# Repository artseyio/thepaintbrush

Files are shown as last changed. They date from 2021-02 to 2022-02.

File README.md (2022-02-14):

# The Paintbrush

A small keyboard design for those who cannot or prefer not use 'traditional' keyboard designs.

*This project aims to create a small keyboard design that is adaptable and flexible. Especially for those with disabilities, those who cannot type on traditional keyboads and those that prefer not use traditional keyboards.*

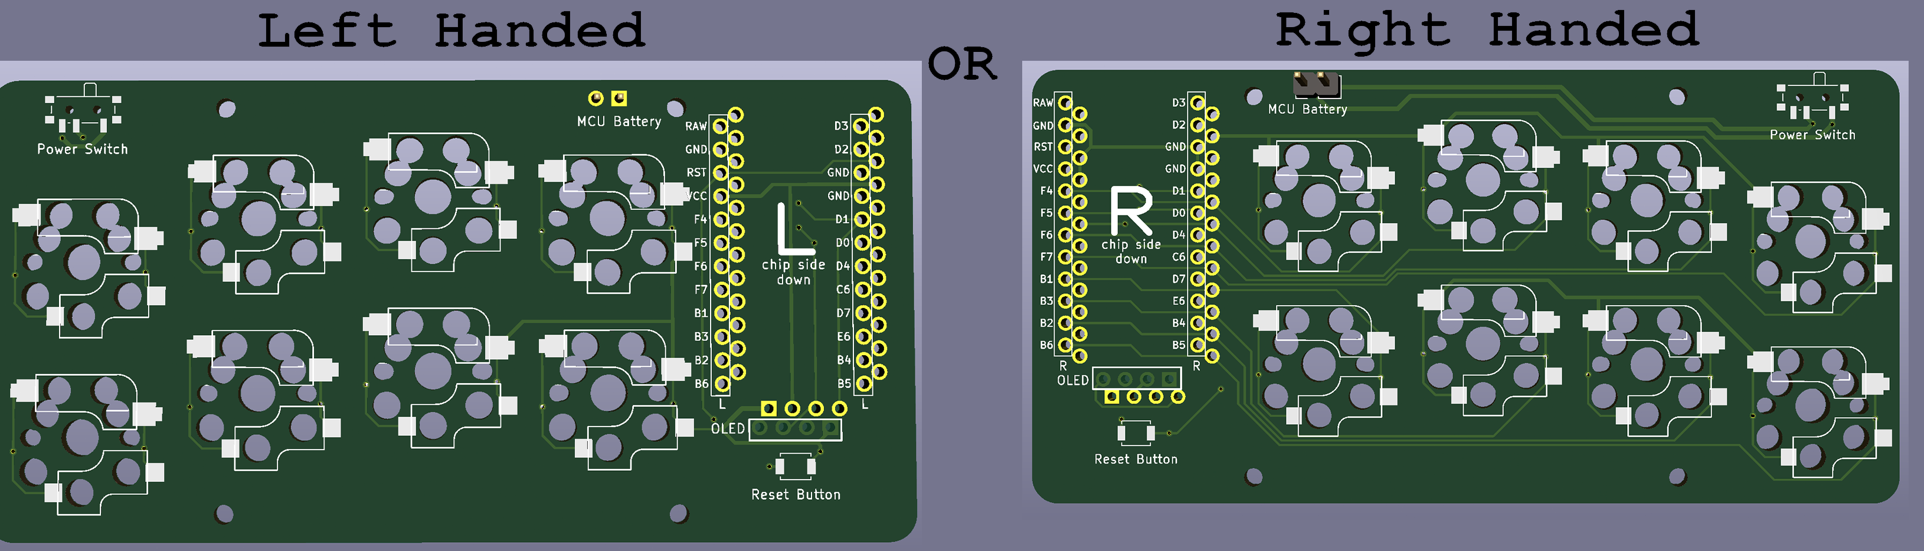
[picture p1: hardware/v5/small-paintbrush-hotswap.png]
Version 5 Rendering


## Versions

The current version of The Painbrush is [version 5](hardware/v5).

*Please refer to the version folders for additional details on building as well as bill of materials.*

## Firmware

QMK and ZMK reference code can be found at [qmk-artsey](https://github.com/artseyio/qmk-artsey/) and [zmk-artsey](https://github.com/artseyio/zmk-artsey/) respectively.

## PCB/Plate Ordering

### PCB

If you'd like to order a PCB you'll need either the main KiCAD file (the ones ending in .pro) or the gerber files (the zip files in the gerber folders). Most PCB makers will ask for ```gerber files``` which will be the zip files in the appropriate ```gerber``` folder. In each hardware revision's folder there will be bottom plate PCB files (KiCAD and gerber) as well as the main PCB files (KiCAD and gerber).

We have been able to confirm both [OSH Park](https://oshpark.com/) and [JLCPCB](https://jlcpcb.com/) can make the paintbrush PCBs.

JLCPCB is usually pretty cheap, even with a minimum order quanity of 5 PCBs. In many cases you can get 5 paintbrush PCBs for under $10 USD if you don't select super fast service or additional options.

### Switch Plate

The switch plate can be made by a number of different companies and there is a file in each hardware revision that ends in ```.step```.

We have been able to confirm [ShapeWays](https://shapeways.com/) and [JLCPCB](https://jlcpcb.com/) have been a very reliable source. They offer a wide range of materials at different price points.

You can also get the switch plate made from a company that does laser cutting but we have not heard which companies may be the best option from the community yet.

### Bottom Plate

The bottom plate can be made by a number of different companies and there is a file in each hardware revision that ends in ```.step```.

We have been able to confirm [ShapeWays](https://shapeways.com/) has been a very reliable source for on demand 3d printing. They offer a wide range of materials at different price points.

You can also get the bottom plate made from a company that does laser cutting but we have not heard which companies may be the best option from the community yet.

## What

A small keyboard hardware design that can be built free of charge for non-commercial use. The design is meant to be used with systems like [ARTSEY.IO](https://www.artsey.io/).

We also work to have our hardware supported by well known open source keyboard firmware projects to make them easier to setup and use.

## Why

There are few keyboard options for those with hand disabilities. The few commercial keyboards 'designed' to address hand disabilities are incredibly expensive and aren't well designed if you consider risk of long term RSI related problems. This project was founded to address these systemic issues.

## Who

Just a human who has had their left hand immobilized for 6 weeks and their right hand injured badly enough to cause typing problems on traditional keyboards for 2 weeks.

## Licensing

Unless otherwise stated all source code is licensed under the [Apache 2 License](LICENSE-APACHE-2.0.txt).

Unless otherwise state all hardware designs are licensed under the [CERN Open Hardware Licence Version 2 - Weakly Reciprocal License](LICENSE-cern_ohl_w_v2.txt).

Unless otherwise stated the non source code and non hardware design contents of this repository are licensed under a [Creative Commons Attribution-NonCommercial-ShareAlike 4.0 International License](LICENSE-CC-Attribution-NonCommercial-ShareAlike-4.0-International.txt)

## Commercial Licencing

If you're interested in commercial licencing of our designs, please contact KemoNine for details. Their e-mail can be found in the git log. When contacting KemoNine please include (at a minimum) your name, your company/store's website, how you plan to sell the designs and why you'd like to sell the designs.

*Please note: this applies to ANY sales that are not 'at cost' or would result in a profit (online stores, group buys, sales to friends, etc)*

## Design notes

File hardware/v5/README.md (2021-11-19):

# Paintbrush Version 5

This is the fifh hardware design of the Paintbrush mini keyboard. This version adds MX switch support, a plate for MX builds and moves the MCU to a better location to accomodate thicker USB cables. The silk screens were also overhauled and can be used to guide a build without referencing these instructions.

Please see the following sections for details about this hardware version.

## Rendering

Version 5 Rendering

## Features

- *Reversable* PCB
  - Can be built left *OR* right handed
- Pro Micro compatible MCU foot print
- Kalih Choc v1 mechanical switches *OR* MX mechanical switches
- OLED support (optional)
- Slide switch that can be used as a power switch (optional)
- Switch plate (required for MX switch builds)
- Reset button (optional)
- Bottom plate (optional)

## Bill of Materials

Please note: the provided links are for reference. Most of these products can be found in more than one store.

For MX switch builds you'll need a switch plate, hot swap sockets and switches for your build. The below switch and socket options are for choc switch builds.

| Component | Part Information | Quantity | Purchase |
| --- | --- | --- | --- |
| Pro Micro MCU | Any pro micro compatible MCU that supports ZMK or QMK | 1 | N/A |
| Kalih Choc v1 Switches | Kailh low profile Switch 1350 Chocolate Keyboard Switch | 8 | [AliExpress](https://www.aliexpress.com/item/32959996455.html) |
| Kalih Hot Swap Sockets (optional if directly soldering switches) | Kailh hot swap Socket for low profile 1350 Chocolate Switches | 8 | [AliExpress](https://www.aliexpress.com/item/33023283633.html) |
| Optional OLED | Any SSD1306 I2C OLED supported by or ZMK | 1 | N/A |
| Optional Power Switch | C&K PCM12SMTR | 1 | [DigiKey](https://www.digikey.com/en/products/detail/c-k/PCM12SMTR/1640112?s=N4IgTCBcDaIAoGECyBGCBdAvkA) |
| Optional Reset button | Omron Electronics Inc-EMC Div B3U-1000P | 1 | [DigiKey](https://www.digikey.com/en/products/detail/omron-electronics-inc-emc-div/B3U-1000P/1534338) |
| Optional Bottom Plate | The bottom plate for the PCB, attach with M2 stand offs and screws | 1 | N/A |
| Optional M2 stand offs | Stand offs can be used to attach the bottom plate or add a mild angle to the obard | 2-4 | N/A |
| Optional Battery | A *lithium* battery for powering the board, we recommend 10440 or lithium polymer batteries | 1 | N/A |

## Bottom Plate

The bottom plate is wholly optional for this build. We strongly recommend including it as part of your PCB order or 3d printing it in [PA12](https://www.shapeways.com/materials/multi-jet-fusion-pa12/) or [PA12-GB](https://www.shapeways.com/materials/multi-jet-fusion-pa12gb/) at [ShapeWays](https://www.shapeways.com/) if you want a bottom plate.

The bottom plate is available as a [step file](small-paintbrush-hotswap-bottom.step) if you'd like to have it created via CNC or 3d printing independent of your PCB order.

The bottom plate can be attached using standard M2 stand offs and screws.

## Build Instructions

1. Solder hot swap sockets
    - Please note: the sockets are soldered to the **underside** of the PCB
1. Solder power switch if being used
1. Solder reset button if being used
1. Solder pro micro compatible mcu
1. Solder OLED if being used
1. Solder one pad of power header to appropriate pro micro pin if being used
1. Solder battery to power header (if being used) and ground
1. Populate switches if using hot swap sockets
1. Flash chosen firmware

## Soldering Quick References

### Left Handed Builds

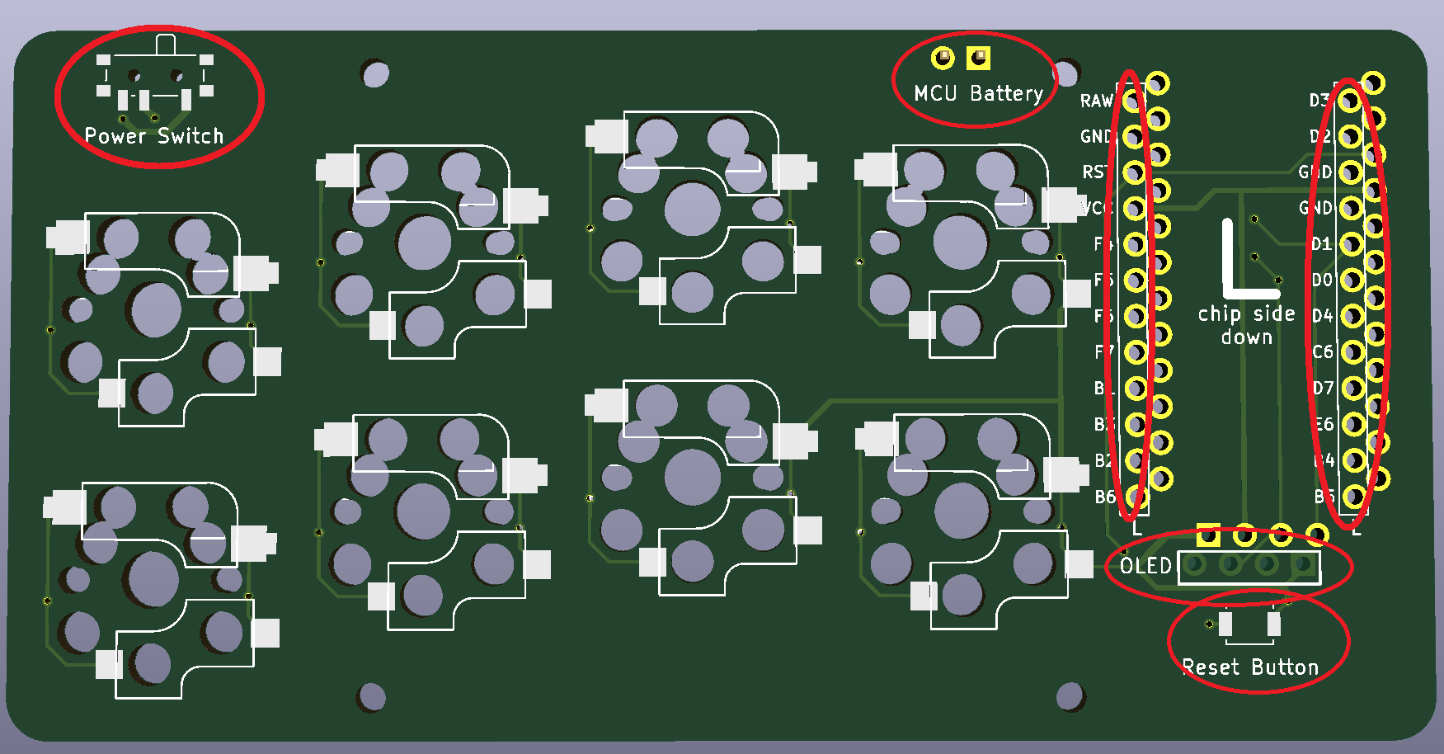
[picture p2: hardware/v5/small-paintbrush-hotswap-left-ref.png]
Version 5 Left Handed Build Quick Ref


### Right Handed Builds

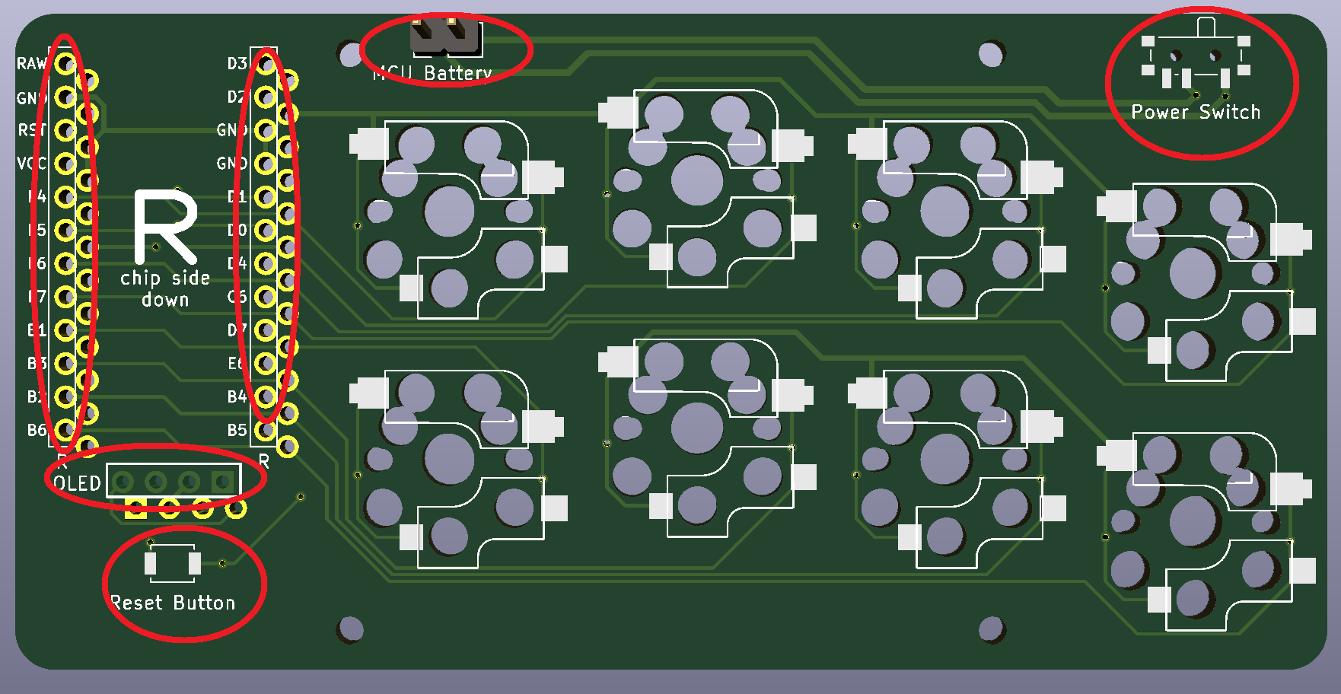
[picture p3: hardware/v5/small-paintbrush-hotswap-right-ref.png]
Version 5 Right Handed Build Quick Ref


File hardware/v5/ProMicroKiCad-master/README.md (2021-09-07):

Pro Micro library for KiCAD
=======================================

This repo includes Pro Micro library.

### Variants
* ProMicro.kicad_mod - The default variant
* ProMicro-NoSilk.kicad_mod - No silkscreen guides
* ProMicro-EnforcedTop.kicad_mod - Covers the Pro Micro side of all pads with soldermask to make reverse-side mounting impossible.

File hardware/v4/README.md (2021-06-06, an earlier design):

# Paintbrush Version 4

This is the fourth hardware design of the Paintbrush mini keyboard. This version removes the 'leg' from version 3 and moves the secondary features (switch/reset button) to a more user friendly location at the top of the board.

Please see the following sections for details about this hardware version.

## Rendering

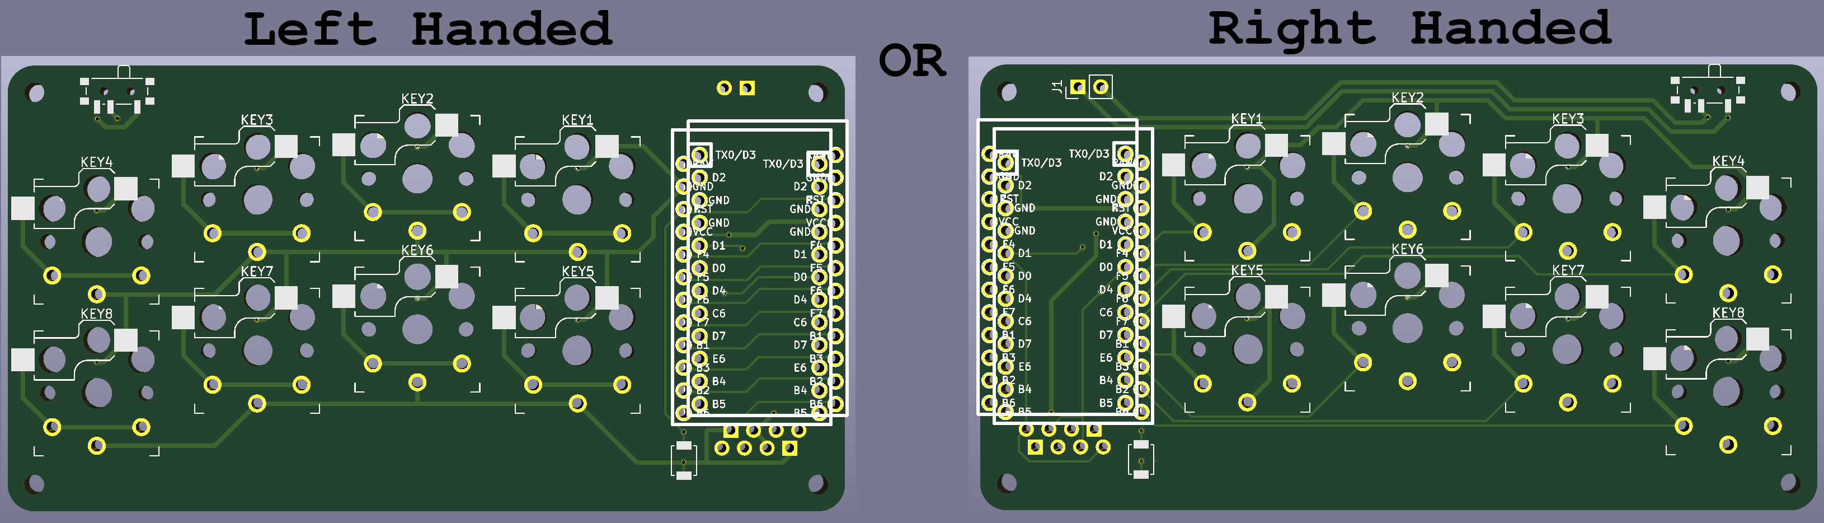
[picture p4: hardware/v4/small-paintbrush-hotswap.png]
Version 4 Rendering


## Features

- *Reversable* PCB
  - Can be built left *OR* right handed
- Pro Micro compatible MCU foot print
- Kalih Choc v1 mechanical switches
  - Soldered directly *OR* using kalih hot swap sockets
- OLED support (optional)
- Slide switch that can be used as a power switch (optional)
- Reset button (optional)
- Bottom plate (optional)

## Bill of Materials

Please note: the provided links are for reference. Most of these products can be found in more than one store.

| Component | Part Information | Quantity | Purchase |
| --- | --- | --- | --- |
| Pro Micro MCU | Any pro micro compatible MCU that supports ZMK or QMK | 1 | N/A |
| Kalih Choc v1 Switches | Kailh low profile Switch 1350 Chocolate Keyboard Switch | 8 | [AliExpress](https://www.aliexpress.com/item/32959996455.html) |
| Kalih Hot Swap Sockets (optional if directly soldering switches) | Kailh hot swap Socket for low profile 1350 Chocolate Switches | 8 | [AliExpress](https://www.aliexpress.com/item/33023283633.html) |
| Optional OLED | Any SSD1306 I2C OLED supported by or ZMK | 1 | N/A |
| Optional Power Switch | C&K PCM12SMTR | 1 | [DigiKey](https://www.digikey.com/en/products/detail/c-k/PCM12SMTR/1640112?s=N4IgTCBcDaIAoGECyBGCBdAvkA) |
| Optional Reset button | Omron Electronics Inc-EMC Div B3U-1000P | 1 | [DigiKey](https://www.digikey.com/en/products/detail/omron-electronics-inc-emc-div/B3U-1000P/1534338) |
| Optional Bottom Plate | The bottom plate for the PCB, attach with M2 stand offs and screws | 1 | N/A |
| Optional M2 stand offs | Stand offs can be used to attach the bottom plate or add a mild angle to the obard | 2-4 | N/A |
| Optional Battery | A *lithium* battery for powering the board, we recommend 10440 or lithium polymer batteries | 1 | N/A |

## Bottom Plate

The bottom plate is wholly optional for this build. We strongly recommend including it as part of your PCB order or 3d printing it in [PA12](https://www.shapeways.com/materials/multi-jet-fusion-pa12/) or [PA12-GB](https://www.shapeways.com/materials/multi-jet-fusion-pa12gb/) at [ShapeWays](https://www.shapeways.com/) if you want a bottom plate.

The bottom plate is available as a [step file](small-paintbrush-hotswap-bottom.step) if you'd like to have it created via CNC or 3d printing independent of your PCB order.

The bottom plate can be attached using standard M2 stand offs and screws.

## Build Instructions

1. Solder hot swap sockets if being used
    - Please note: the sockets are soldered to the **underside** of the PCB
1. Solder power switch if being used
1. Solder reset button if being used
1. Solder switches if *NOT* using hot swap sockets
1. Solder pro micro compatible mcu
1. Solder OLED if being used
1. Solder one pad of power header to appropriate pro micro pin if being used
1. Solder battery to power header (if being used) and ground
1. Populate switches if using hot swap sockets
1. Flash chosen firmware

## Soldering Quick References

### Left Handed Builds

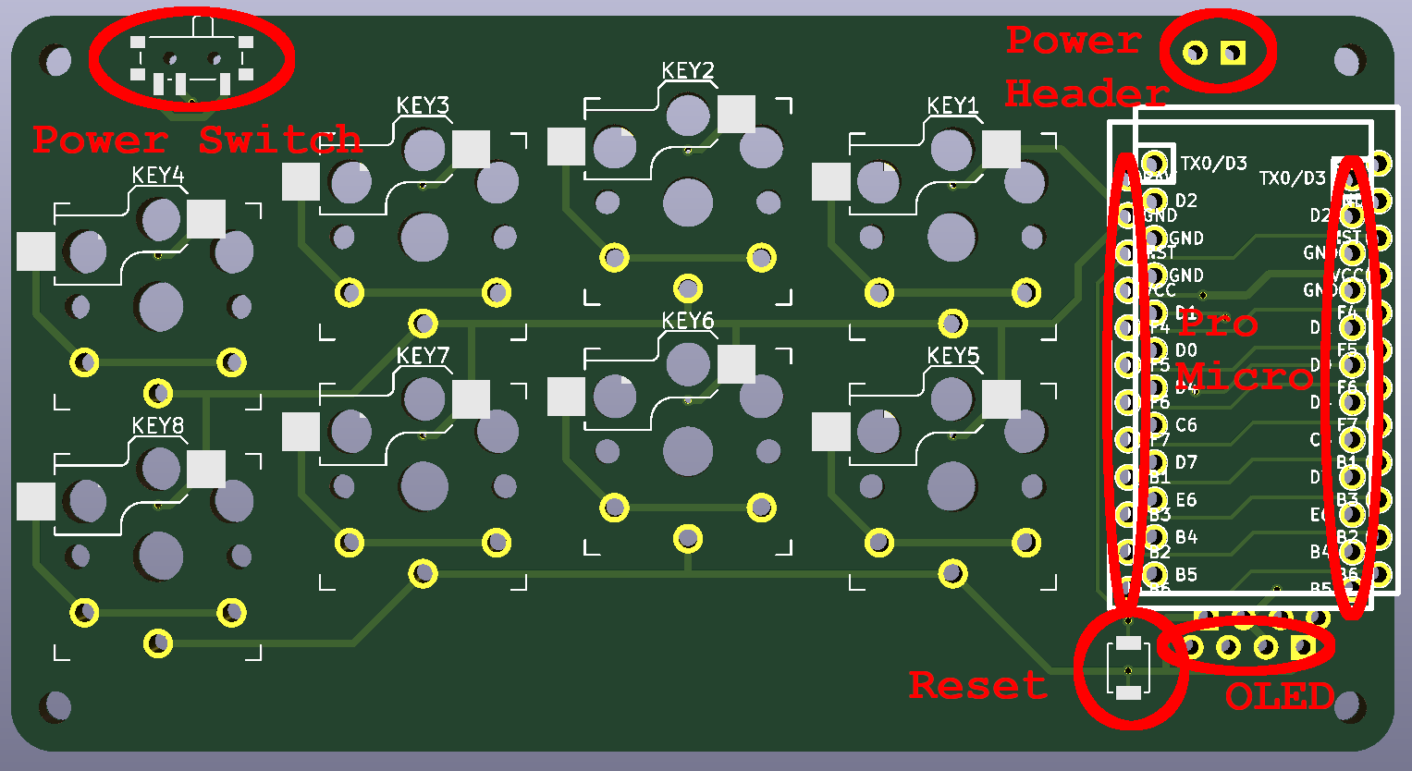
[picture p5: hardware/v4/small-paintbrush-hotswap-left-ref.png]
Version 4 Left Handed Build Quick Ref


### Right Handed Builds

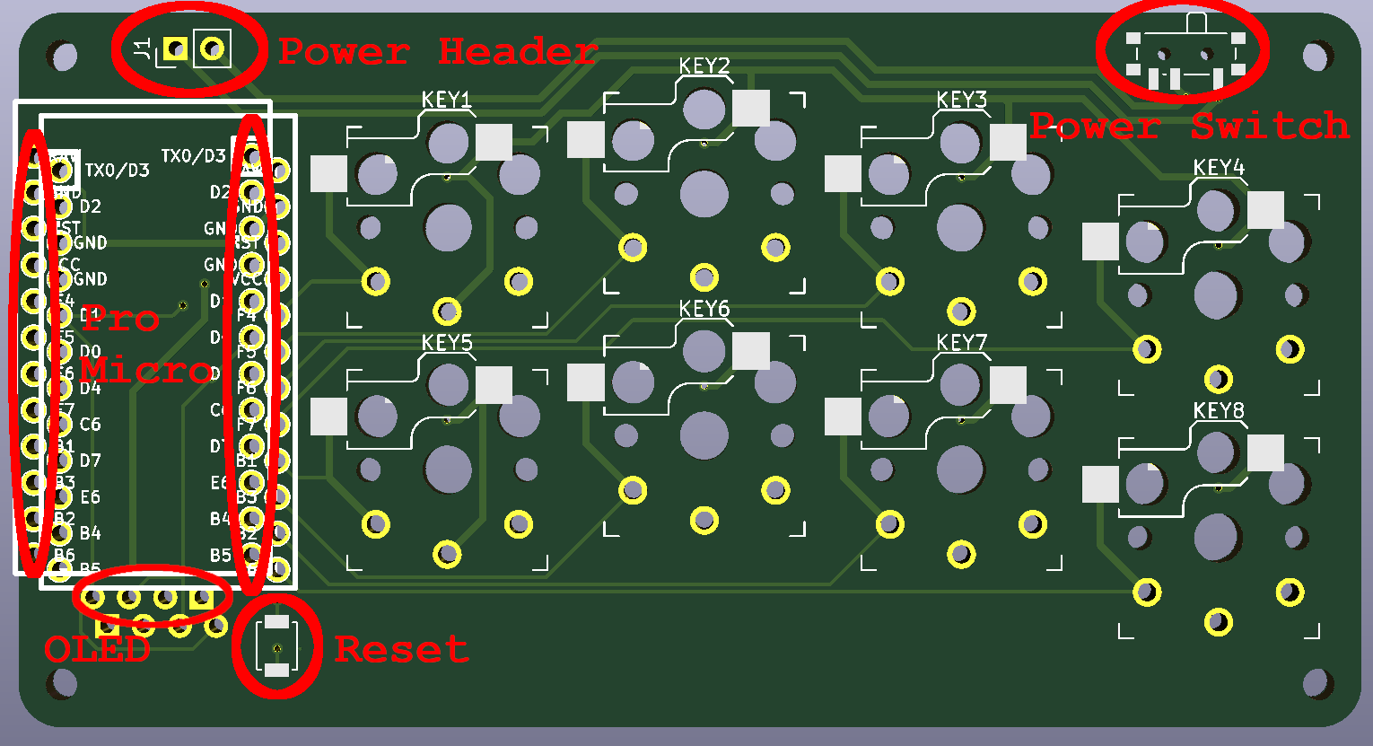
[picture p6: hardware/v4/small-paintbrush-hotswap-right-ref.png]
Version 4 Right Handed Build Quick Ref


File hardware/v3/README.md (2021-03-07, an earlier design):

# Paintbrush Version 3

This is the third hardware design of the Paintbrush mini keyboard. This version includes a 'leg' for two extra thumb keys and a mild row offset. This version also allows for the MCU orientation to be consistent for left and right handed builds.

Please see the following sections for details about this hardware version.

## Features

- *Reversable* PCB
  - Can be made left *OR* right handed
- Pro Micro compatible MCU foot print
- Kalih Choc v1 mechanical switches
  - Soldered directly *OR* using hot swap sockets
- OLED support (optional)
- Slide switch that can be used as a power switch (optional)
- Reset button (optional)

## Bill of Materials

Please note: the provided links are for reference. Most of these products can be found in more than one store.

| Component | Part Information | Quantity | Purchase |
| --- | --- | --- | --- |
| Pro Micro MCU | Any pro micro compatible MCU that supports ZMK or QMK | 1 | N/A |
| Kalih Choc v1 Switches | Kailh low profile Switch 1350 Chocolate Keyboard Switch | 8 | [AliExpress](https://www.aliexpress.com/item/32959996455.html) |
| Kalih Hot Swap Sockets (optional if directly soldering switches) | Kailh hot swap Socket for low profile 1350 Chocolate Switches | 8 | [AliExpress](https://www.aliexpress.com/item/33023283633.html) |
| Optional OLED | Any SSD1306 I2C OLED supported by or ZMK | 1 | N/A |
| Optional Power Switch | C&K PCM12SMTR | 1 | [DigiKey](https://www.digikey.com/en/products/detail/c-k/PCM12SMTR/1640112?s=N4IgTCBcDaIAoGECyBGCBdAvkA) |
| Optional Reset button | Omron Electronics Inc-EMC Div B3U-1000P | 1 | [DigiKey](https://www.digikey.com/en/products/detail/omron-electronics-inc-emc-div/B3U-1000P/1534338) |

## Rendering

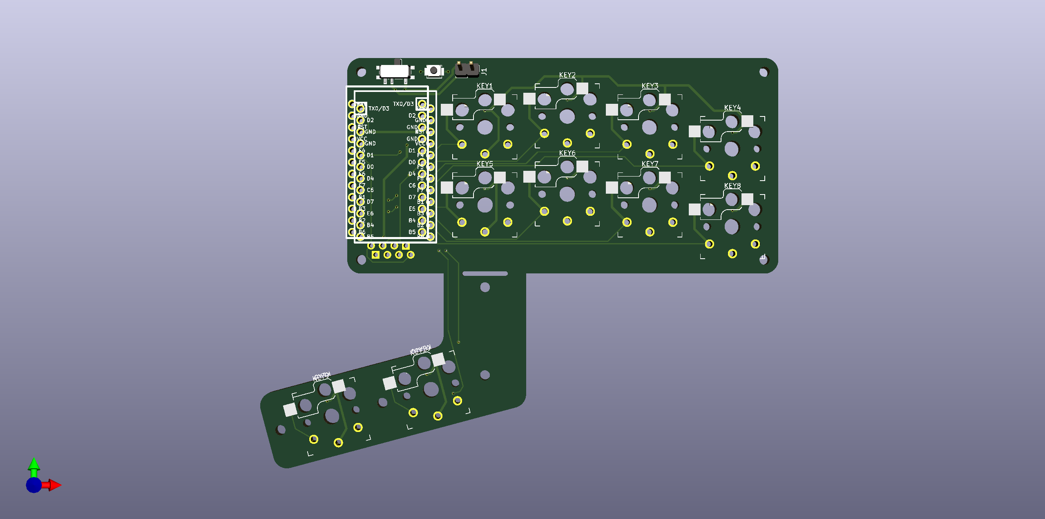
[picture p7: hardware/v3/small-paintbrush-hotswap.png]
Version 3 Rendering


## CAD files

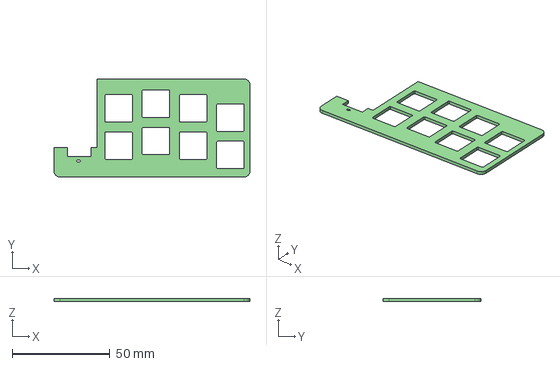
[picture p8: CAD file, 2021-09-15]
hardware/v5/small-paintbrush-hotswap-mxplate.step
100.0 x 50.0 x 1.60 mm

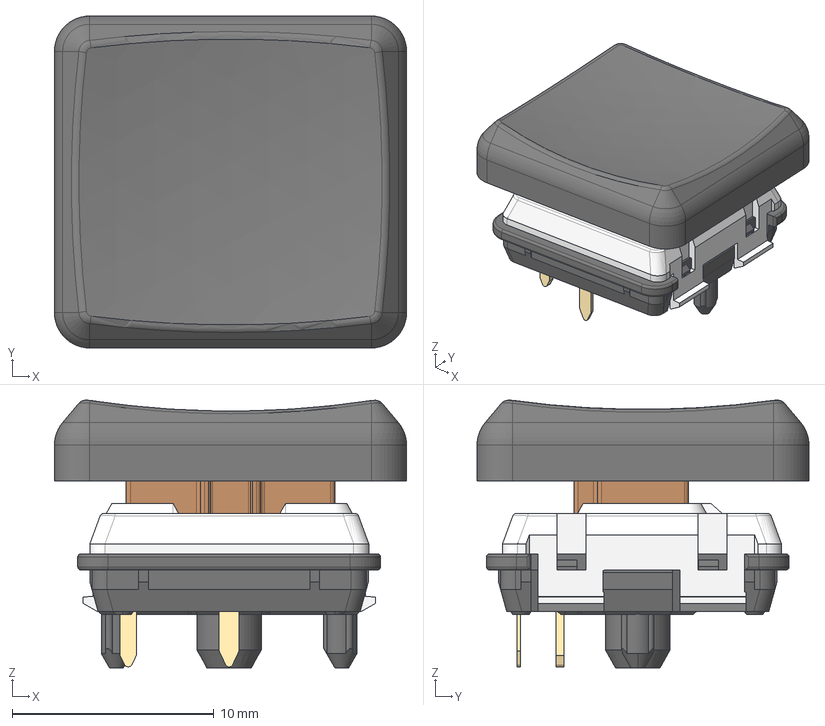
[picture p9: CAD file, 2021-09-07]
hardware/v5/choc-mbk.step
17.4 x 16.4 x 13.3 mm
(Unsaved)
Document x 5

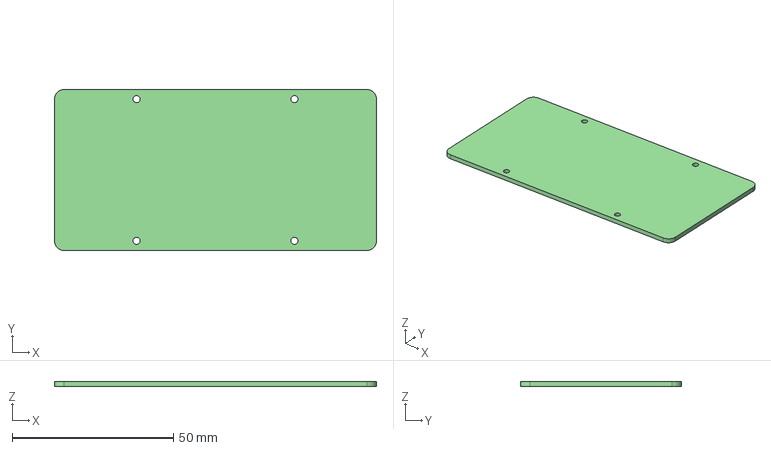
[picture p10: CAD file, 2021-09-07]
hardware/v5/small-paintbrush-hotswap-bottom.step
100.0 x 50.0 x 1.60 mm

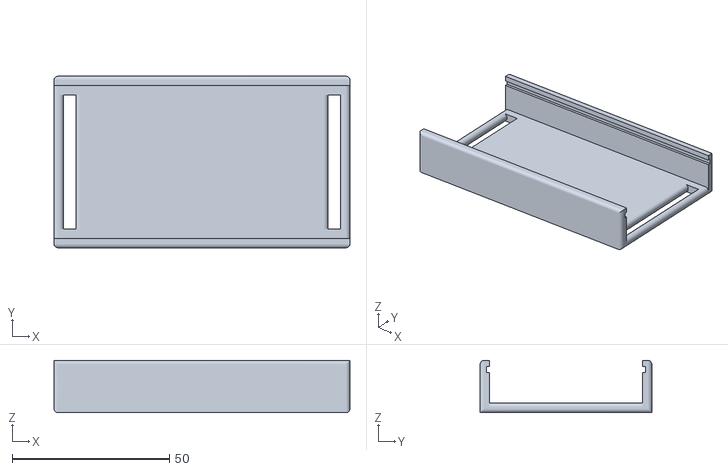
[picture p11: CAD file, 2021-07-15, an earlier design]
hardware/v4/thepalette.stl
94.0 x 54.5 x 16.6

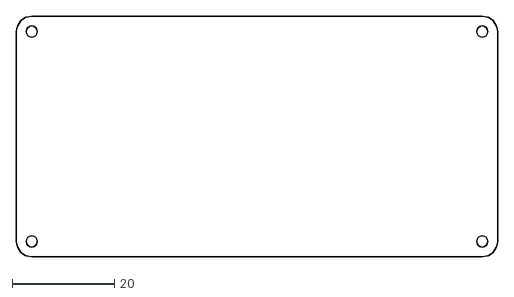
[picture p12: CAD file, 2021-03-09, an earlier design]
hardware/v4/small-paintbrush-hotswap-bottom.dxf
94.0 x 47.0

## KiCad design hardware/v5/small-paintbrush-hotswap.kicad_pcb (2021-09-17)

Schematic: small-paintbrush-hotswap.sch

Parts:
H1: MountingHole; mounting-holes
J1: Conn_01x02; PinHeader_1x02_P2.54mm_Vertical
J2, J3: Conn_01x04; OLED
KEY1, KEY2, KEY3, KEY4, KEY5, KEY6, KEY7, KEY8: SW_Push; MX_Choc_Hotswap
PUSH1, PUSH2: SW_Push; SW_SPST_B3U-1000P
SW1, SW2: SW_SPDT; SW_SPDT_PCM12
U1, U2: ProMicro; promicro

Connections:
GND: J2.1, J3.1, KEY1.1, KEY2.1, KEY3.1, KEY4.1, KEY5.1, KEY6.1, KEY7.1, KEY8.1, PUSH1.2, PUSH2.2, U1.3 (GND), U1.4 (GND), U1.23 (GND), U2.3 (GND), U2.4 (GND), U2.23 (GND)
unnamed: J1.1, SW1.1 (A), SW2.1 (A)
unnamed: J1.2, SW1.2 (B), SW2.2 (B)
R1C1: KEY1.2, U1.20 (F4), U2.20 (F4)
R1C2: KEY2.2, U1.19 (F5), U2.19 (F5)
R1C3: KEY3.2, U1.18 (F6), U2.18 (F6)
R1C4: KEY4.2, U1.17 (F7), U2.17 (F7)
R2C1: KEY5.2, U1.16 (B1), U2.16 (B1)
R2C2: KEY6.2, U1.15 (B3), U2.15 (B3)
R2C3: KEY7.2, U1.14 (B2), U2.14 (B2)
R2C4: KEY8.2, U1.13 (B6), U2.13 (B6)
RST: PUSH1.1, PUSH2.1, U1.22 (RST), U2.22 (RST)
SCL: J2.3, J3.3, U1.6 (SDA), U2.6 (SDA)
SDA: J2.4, J3.4, U1.5 (SCL), U2.5 (SCL)
VCC: J2.2, J3.2, U1.21 (VCC), U2.21 (VCC)

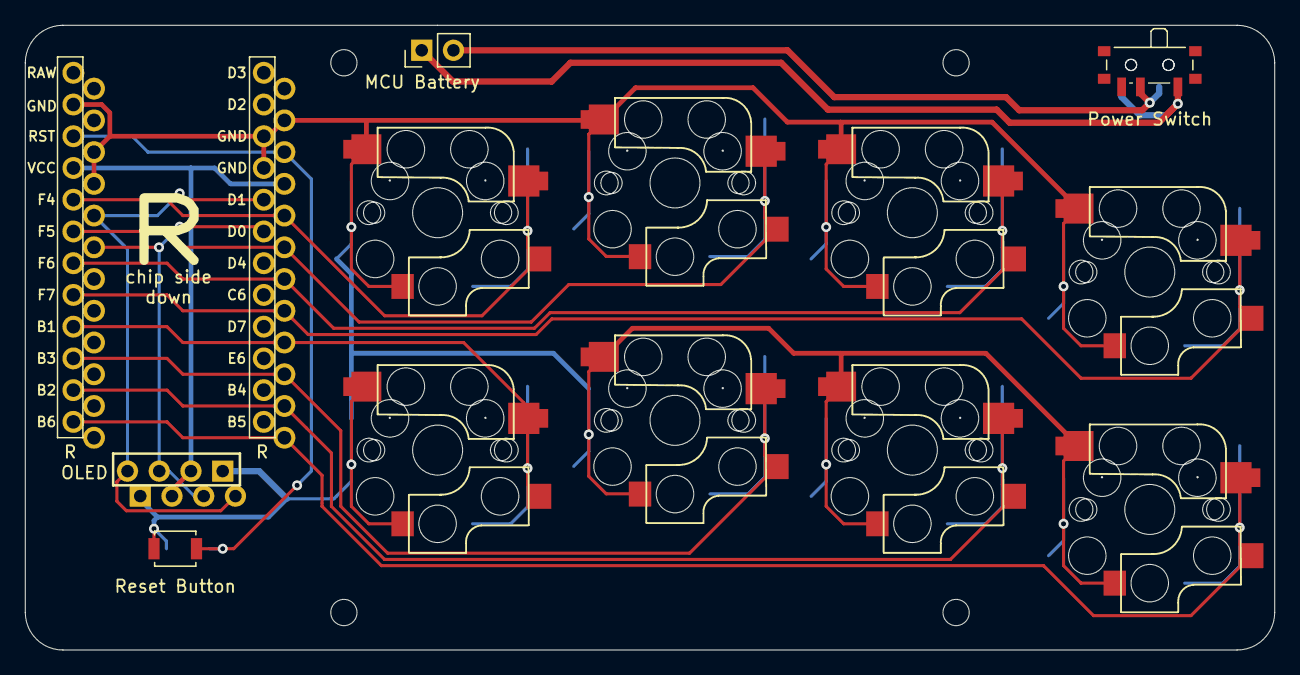
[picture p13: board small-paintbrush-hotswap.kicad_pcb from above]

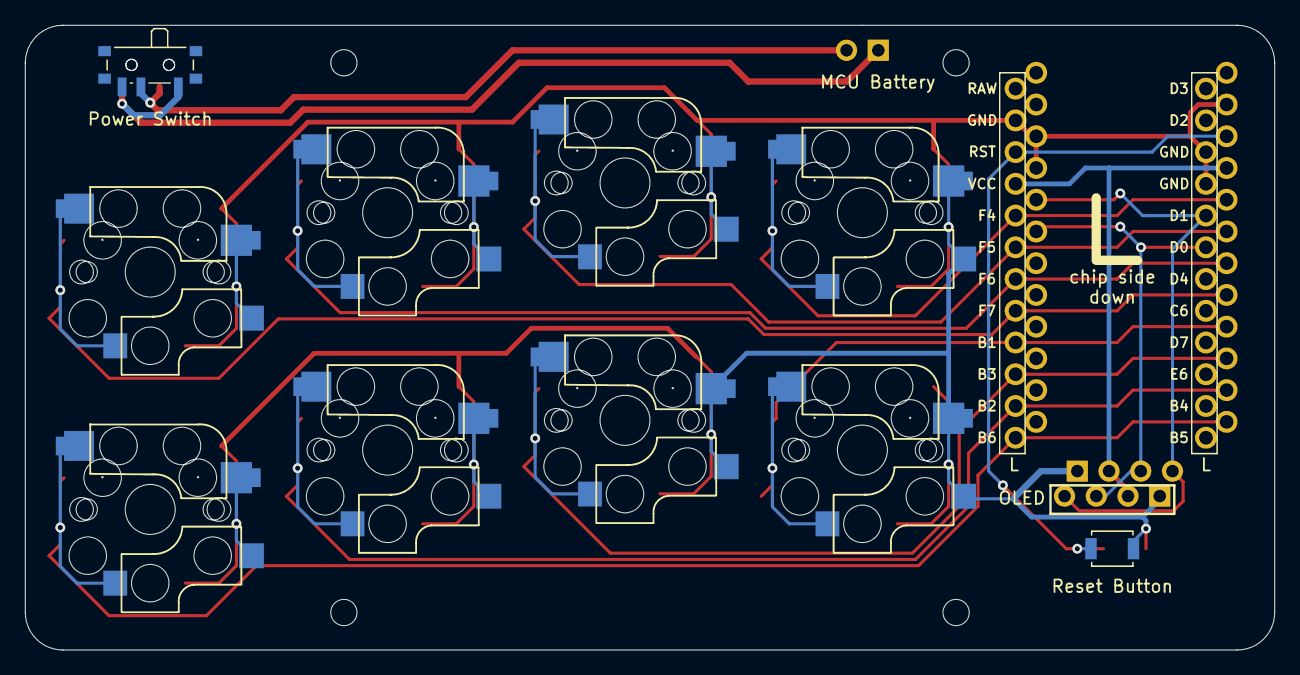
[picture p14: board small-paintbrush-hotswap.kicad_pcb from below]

Board: 2 copper layers, 100.0 x 50.0 mm, 18 parts (4 on the bottom side), 15 nets.

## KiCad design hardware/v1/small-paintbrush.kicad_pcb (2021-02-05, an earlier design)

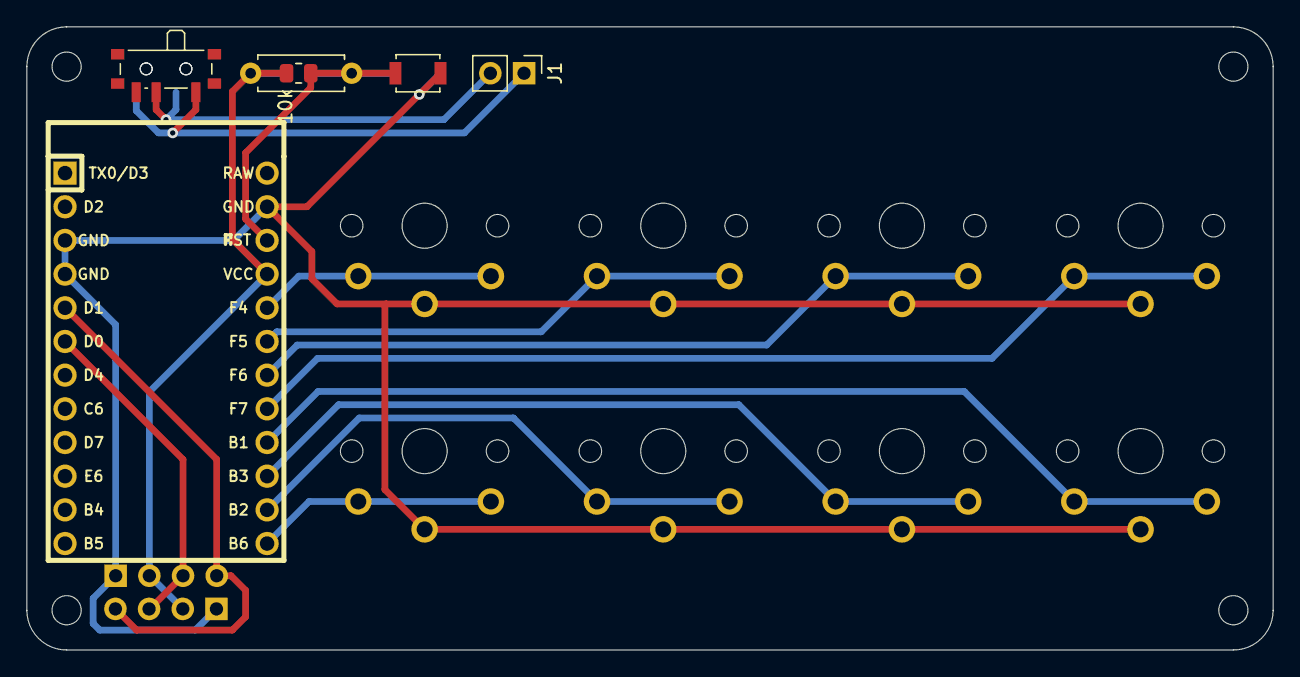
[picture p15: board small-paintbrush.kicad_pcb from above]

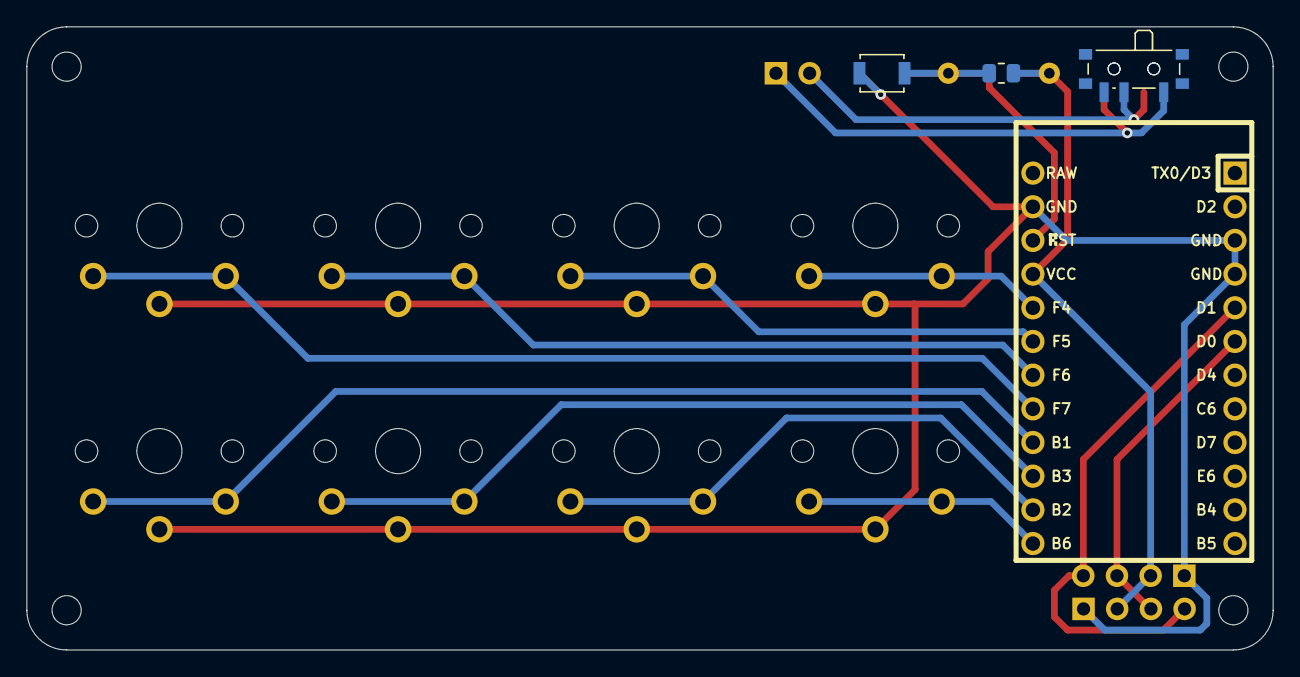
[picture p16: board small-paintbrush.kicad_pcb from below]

Board: 2 copper layers, 94.0 x 47.0 mm, 19 parts (4 on the bottom side), 15 nets.

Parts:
J1: Conn_01x02; PinHeader_1x02_P2.54mm_Vertical
J2, J3: Conn_01x04; OLED
KEY1, KEY2, KEY3, KEY4, KEY5, KEY6, KEY7, KEY8: SW_Push; Kailh-PG1350-1u-reversible-No-Clickhole
PUSH1, PUSH2: SW_Push; SW_SPST_B3U-1000P
R1, R3: 10k; R_0805_2012Metric
R2: 10k; R_Axial_DIN0207_L6.3mm_D2.5mm_P7.62mm_Horizontal
SW1, SW2: SW_SPDT; SW_SPDT_PCM12
U1: ProMicro; ArduinoProMicro

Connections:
GND: J2.1, J3.1, KEY1.1, KEY2.1, KEY3.1, KEY4.1, KEY5.1, KEY6.1, KEY7.1, KEY8.1, PUSH1.2, PUSH2.2, U1.3, U1.4, U1.23
unnamed: J1.1, SW1.1, SW2.1
unnamed: J1.2, SW1.2, SW2.2
unnamed: PUSH1.1, PUSH2.1, R1.1, R2.1, R3.1, U1.22
R1C1: KEY1.2, U1.20
R1C2: KEY2.2, U1.19
R1C3: KEY3.2, U1.18
R1C4: KEY4.2, U1.17
R2C1: KEY5.2, U1.13
R2C2: KEY6.2, U1.14
R2C3: KEY7.2, U1.15
R2C4: KEY8.2, U1.16
SCL: J2.3, J3.3, U1.6
SDA: J2.4, J3.4, U1.5
VCC: J2.2, J3.2, R1.2, R2.2, R3.2, U1.21

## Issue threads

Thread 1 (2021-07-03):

Not enough USB port clearance

mcrosson, 2021-07-03:
When using lower profile headers / non machine pin sockets the MCU sits too low to the PCB to allow most usb connectors to 'fit' ; there isn't enough vertical clearance.

Design needs to be rev'd so there is better usb clearance and/or re-worked around the 'front' of the mcu where the usb port is to facilitate more cable types and designs.

See https://discord.com/channels/771908552818294784/846716279264247888/860252056882249758 for reference and a photo.

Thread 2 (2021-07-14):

add thepalette stl to hardware for V4 PCB

BrokenFlows, 2021-07-14:
Add the [3D printable file from my repo](https://github.com/BrokenFlows/thepalette/blob/main/thepalette.stl) for using thepaintbrush strapped onto something, like a leg. GitHub wouldn't allow me to add an stl to the issue, so I uploaded it at the above link.

mcrosson, 2021-07-15:
Added to sources

Closed 2021-07-15.

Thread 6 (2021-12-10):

Paintbrush V5 basic case.

filibustercrankcase, 2021-12-10:
[Paintbrush V5Rb.zip](https://github.com/artseyio/thepaintbrush/files/7689739/Paintbrush.V5Rb.zip)

This is a simple case to replace the bottom plate of the V5 Paintbrush, and uses M2 heat inserts, similar to these found on AliExpress. https://www.aliexpress.com/item/1005002986258961.html

mcrosson, 2021-12-28:
updated case at https://github.com/filibustercrankcase/Paintbrush-V5-case

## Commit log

2021-02-05 Prep git ignore for kicad import
2021-02-05 Import paintbrush v1 hardware design
    [small-paintbrush-B_Cu.gbr, small-paintbrush-B_Mask.gbr, small-paintbrush-B_SilkS.gbr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]
2021-02-05 Import paintbrush v2 hardware design
    [small-paintbrush-bottom-B_Cu.gbr, small-paintbrush-bottom-B_Mask.gbr, small-paintbrush-bottom-B_SilkS.gbr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]
2021-02-21 Add version 3 of pcb
    [small-paintbrush-B_Cu.gbr, small-paintbrush-B_Mask.gbr, small-paintbrush-B_SilkS.gbr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]
2021-03-07 Import v4 hardware designs
    [small-paintbrush-B_Cu.gbr, small-paintbrush-B_Mask.gbr, small-paintbrush-B_SilkS.gbr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]
2021-03-08 Convert v4 bottom plate to a step file for easier 3d printing or CNC
    [small-paintbrush-hotswap-bottom.step]
2021-03-09 Add dxf file for v4 base
    [small-paintbrush-hotswap-bottom.dxf]
2021-03-19 Rev v4 to add tap holes
    [small-paintbrush-hotswap.kicad_pcb, small-paintbrush-hotswap.sch]
2021-03-23 Update v4 hardware to include stand off holes and move the reset button / power switch to better locations
    [small-paintbrush-B_Cu.gbr, small-paintbrush-B_Mask.gbr, small-paintbrush-B_SilkS.gbr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]
2021-04-17 Remove unnecessary files ; fix v4 bottom plate size
    [small-paintbrush-Edge_Cuts.gbr, small-paintbrush-F_Cu.gbr, small-paintbrush-F_Mask.gbr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]
2021-05-08 Update gerber files for v4 pcb
    [small-paintbrush-Edge_Cuts.gbr, small-paintbrush-F_Cu.gbr, small-paintbrush-F_Mask.gbr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]
2021-06-30 Add additional information on how to get pcbs/bottom plates made
2021-07-15 Add stl file for the hand 'strap' case
    [thepalette.stl]
2021-07-31 Add initial v5 hardware
    [small-paintbrush-hotswap-B_Cu.gbr, small-paintbrush-hotswap-B_Mask.gbr, small-paintbrush-hotswap-B_SilkS.gbr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]
2021-09-07 v5 of the paintbrush with choc and mx hot swap switches (pcb size changed)
    [choc-mbk.step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]
2021-09-15 update v5 plate to allow access to reset button and be notched to allow room for the oled on plate builds
    [small-paintbrush-hotswap-mxplate.kicad_pcb, small-paintbrush-hotswap-mxplate.step]
2021-09-17 fix missing trace and gerbers for v5
    [small-paintbrush-hotswap-B_Cu.gbr, small-paintbrush-hotswap-B_Mask.gbr, small-paintbrush-hotswap-B_SilkS.gbr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]
2021-11-19 update main readme for v5. add readme for v5 with additional board details.
2021-12-05 Fix v5 bottom gerber files, add gm1 and modify zip file
    [small-paintbrush-hotswap-bottom-Edge_Cuts.gm1]
